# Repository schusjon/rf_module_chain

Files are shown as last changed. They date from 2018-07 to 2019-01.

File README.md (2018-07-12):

# Overview

The aim of the project is to develop a chain of RF-modules which can be connected in series. The most common connector for RF applications is the SMA connector. Because of the high purchase price, the idea to use another connector e.g. PCI Express has existed for quite some time. The main advantage over other connectors is the comparatively low price. Moreover, it can be used up to a frequency of about 500 MHz and the male connector can be easily included on the circuit board. 

[Bild 1]: images/chain.PNG
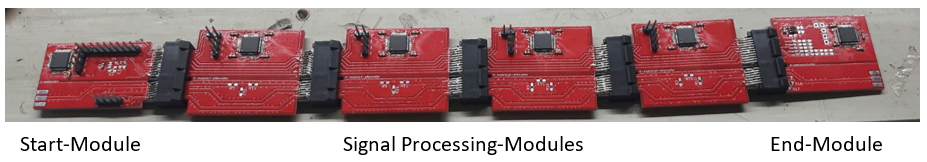
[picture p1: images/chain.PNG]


A means of digital communication should be implemented throughout the chain, an expansion that distinguishes this project from previous, unfinished attempts. The high amount of contacts the PCI-E connector provides facilitates this endeavor.
The chain starts with a special start-module including pin headers for the power supply, as will be explained later.
We expect that the following voltages will cover most conceivable scenarios:

Voltage Rails

|  +5V | -5V  |  3.3V | +12V  | -12V  |
|---|---|---|---|---|

Again, the chosen PCI connector allows for all those different voltage rails and with a current handling of 1A per pin, distributing power to the chain can be done with the same connector.
To feed the chain with the RF-Signal, one SMA connector on the start-module is unavoidable. For further experiments it is useful to add two additional RF inputs. 
These can be used for a reference signal or any auxiliary signal. In this project we limit ourselves to designing only the traces and basic interfacing for these signals on the boards. 
To receive the signal from the chain, a further SMA connecter is used on the end module. 

## Signal Chain

The signal chain consists of different modules, all of which have a few components and properties in common:
All links within the chain are established with PCI-E 36 connectors, all modules bear either a straddle mount receptacle, card-edge fingers or both to interface with neighboring modules.
Each one is equipped with a STM32F0 microprocessor for data transmission and control purposes. 
They utilize their internal RC oscillator to help minimize cost and prevent clock spill into the RF signals.
A 4pin header is used to program these processors with a ST-Link USB adaptor. A fifth pin adjacent to the programming connector serves in conjunction with a jumper as a power switch for the processor on this module only. 
Connected during normal operation, the jumper can be removed to shut off the processor of a single module without cutting the power of the rest of the chain. (Due to the nature of the daisy chain, communication will be interrupted as well)
The modules incorporate separate ground planes for RF and data/power circuits. 
The RF ground is continuous on the back of the PCB to improve impedance control. Via stitching and a defined trace width and aura (1mm width, 0.15mm aura) of the RF signal traces on the 1.6mm FR4 PCBs yield an impedance close to 50 Ohms (with the properties of the laminate causing deviations). 
A series of solder pads on the modules allow linking those ground planes at virtually any point in the chain if the need arises.

[Bild 2]: images/bottom.PNG
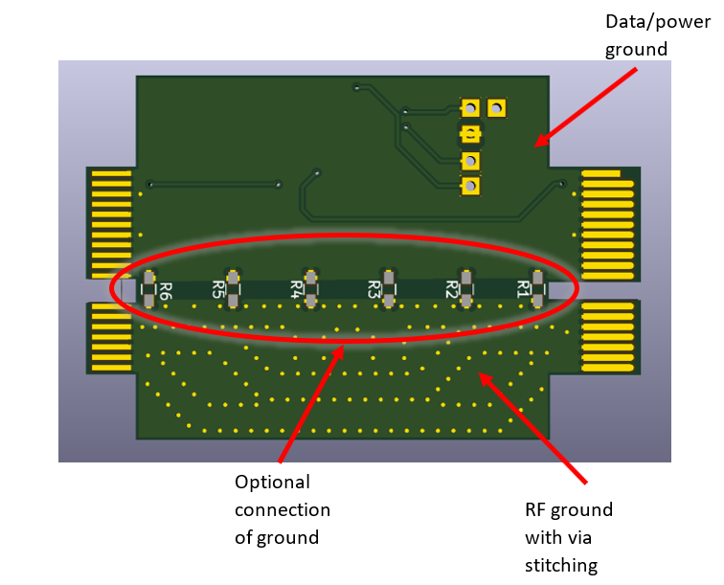
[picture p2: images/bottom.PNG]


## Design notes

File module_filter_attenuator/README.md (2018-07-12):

# Filter Attenuator Modules

**The filter/attenuator modules** come in two topologies, PI and T. Solder pads (0603 in metric system) allow for custom filters and attenuators. Identical except for the filter configuration, both modules pass REF and AUX unaltered. The processor can be programmed with information about the implemented filter, making its properties computer-readable. While it does not provide any control functionality at this moment, it is conceivable to utilize RF switches to select different attenuations or frequencies. (the SKY 13XXX range from Skyworks Solutions appears to be promising and cost effective)

The prototype PI-attenuator was equipped with 18 Ohms for R7 and R9 and 300 ohms for R8, selected from the E24 series.

The calculated values for 3dB attenuation would have been 17.6 ohms and 292 ohms respectively.

The T attenuator was implemented with 10dB of attenuation, with  the resistor values 27 and 36 ohms ( instead of the theoretical 26.0 and 35.1 ohms)

[Bild 1]: images/bottom-pi-att.PNG

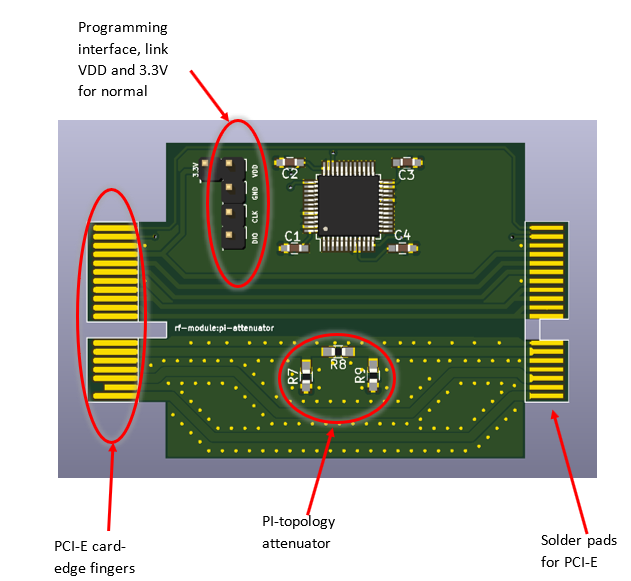
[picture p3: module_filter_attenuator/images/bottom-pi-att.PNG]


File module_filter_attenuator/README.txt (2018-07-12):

R1, R2, R3, R6, R7, R8 werden nicht bestückt!
Filter/Dämpfungsglied vorerst nicht bestücken!

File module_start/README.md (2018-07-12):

# Start Module

**The input/start module** additionally features input connectivity for power and signals:

Standard 2.54mm pin headers serve as power inputs, thus allowing for easy assembly of custom breakout cables. The same holds true for the RX and TX signals, enabling the user to use his favorite UART converter or control the chain with a single board computer. Additional ground pins might be added in following revisions to facilitate interfacing.

The RF signal has a female SMA receptacle, the two additional signals (REF and AUX) terminate to solder pads that allow connection of coax cables or pin headers.

The input module also hosts a 3.3V regulator that supplies the whole chain. Solder pads are prepared for different types of SOT 23-5 LDOs with their respective circuitry.

At the moment, the installed processor does not add any exclusive functionality and is simply another link in the daisy chain. A possible future implementation would be the detection of input signals or power supply voltages to help troubleshoot larger experimental setups. Conversely, this component could be cut entirely for cost optimization. Especially with suitable detectors like the AD 8307 being in the 10€ price range.

[Bild 1]: images/start_description.PNG

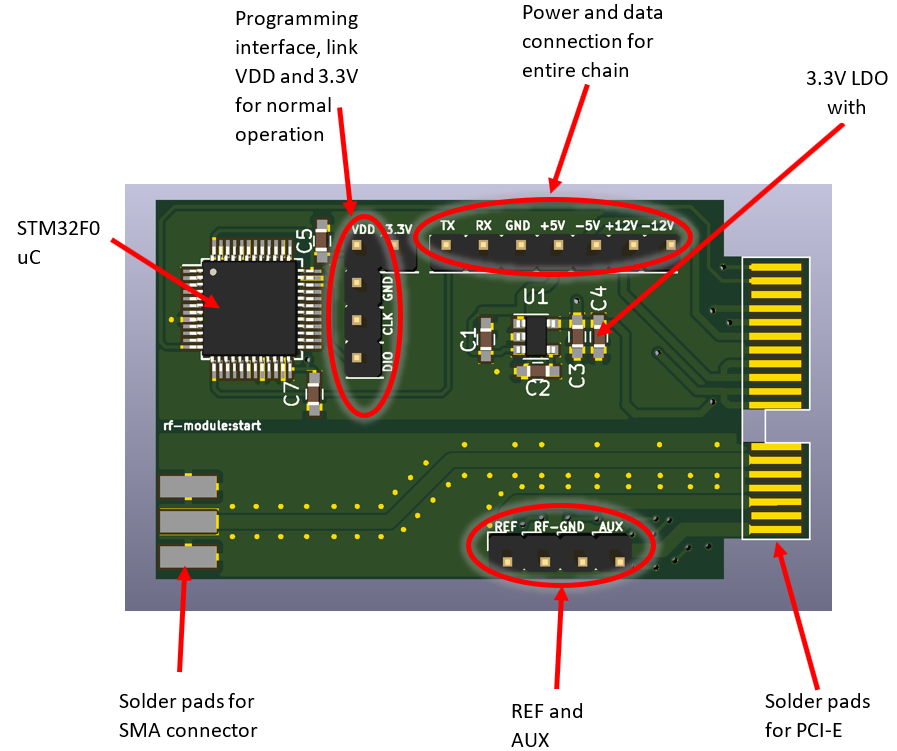
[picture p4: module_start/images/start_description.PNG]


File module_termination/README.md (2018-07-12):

# Termination Module

**The termination/end module** includes status LEDs to check the power busses and the link status of the chain. Two of them are controlled by the uC and are user programmable. The two additional RF signals, REF and AUX are terminated on the module with 50 ohms.

The output is implemented as a female SMA receptacle.

The prototype carries its own 3.3V LDO due to the critical role of the embedded processor. This last link in the chain reorganizes all data received from preceding modules and transmits them to the control computer. This individual power supply could have offered additional debugging and troubleshooting information but was deemed unnecessary in early test and was therefore omitted from later designs.

Further development could include an automated power supply check: A passive resistor network of voltage dividers and pullups should be enough to generate an unambiguous digital pattern that would enable the uC to read the status of the connected supplies.

[Bild 1]: images/bottom_termination.PNG

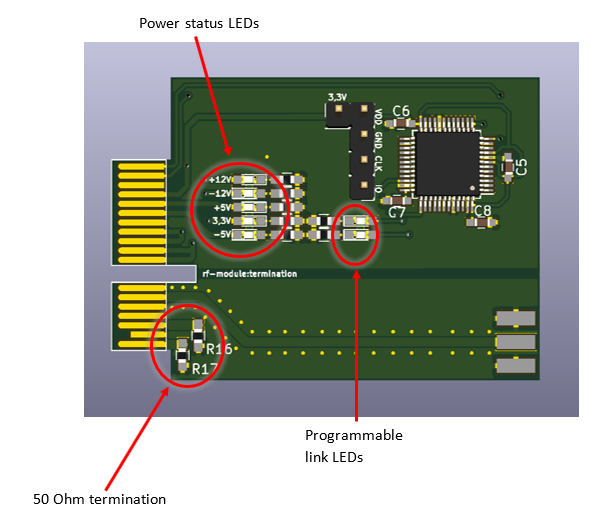
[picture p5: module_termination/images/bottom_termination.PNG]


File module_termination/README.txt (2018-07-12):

R6, R7, R8, R9, R10, R11, R12, R13 werden nicht bestückt!
C2, C4 nicht bestücken! (für anderen Spannungsregler)
Bei LEDs: Punkt markiert Kathode
Widerstände bei Bedarf auf nächst höheren Wert aufrunden

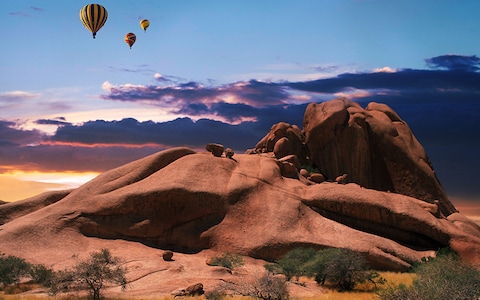
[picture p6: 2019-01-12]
serial_communication/d3.jpg

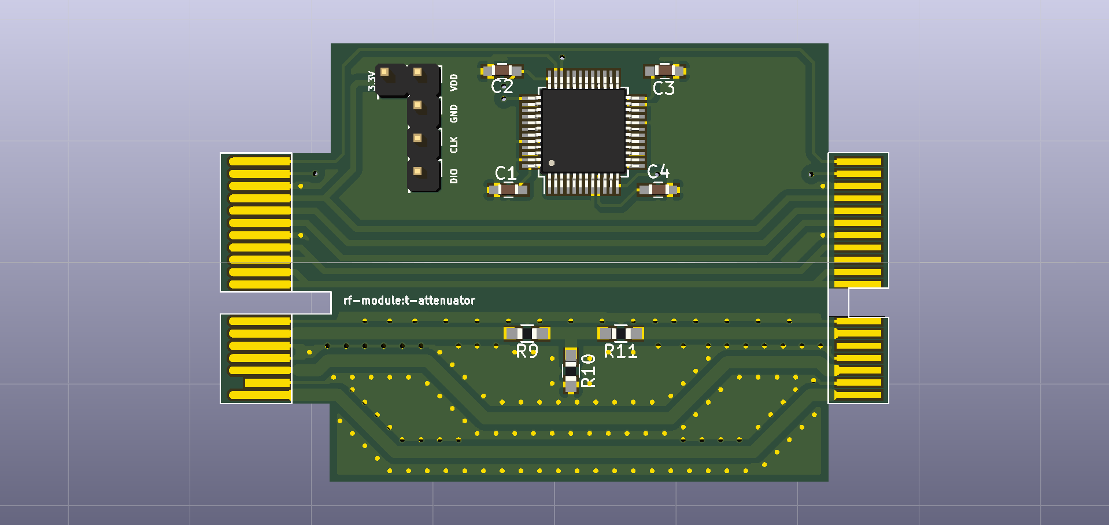
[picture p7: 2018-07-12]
module_filter_attenuator/rflego_t_att_mit_Bauteile.png

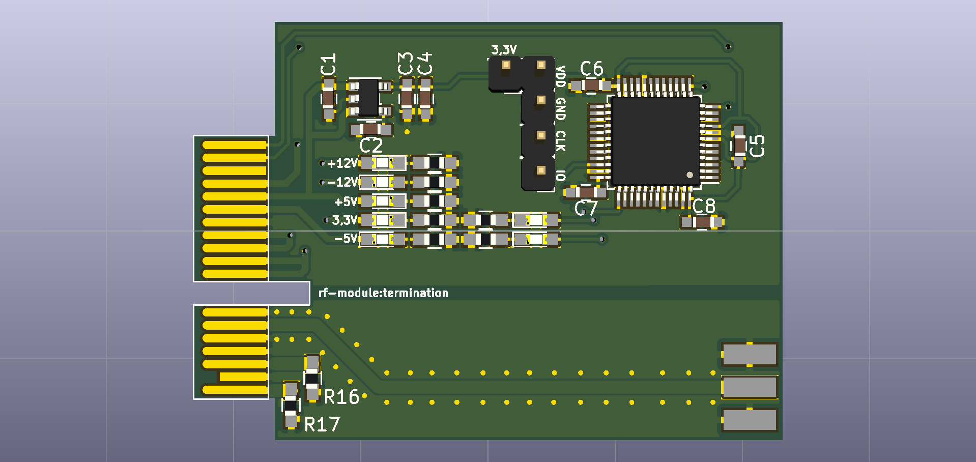
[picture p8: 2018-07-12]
module_termination/rflego_termination_mit_Bauteile.png

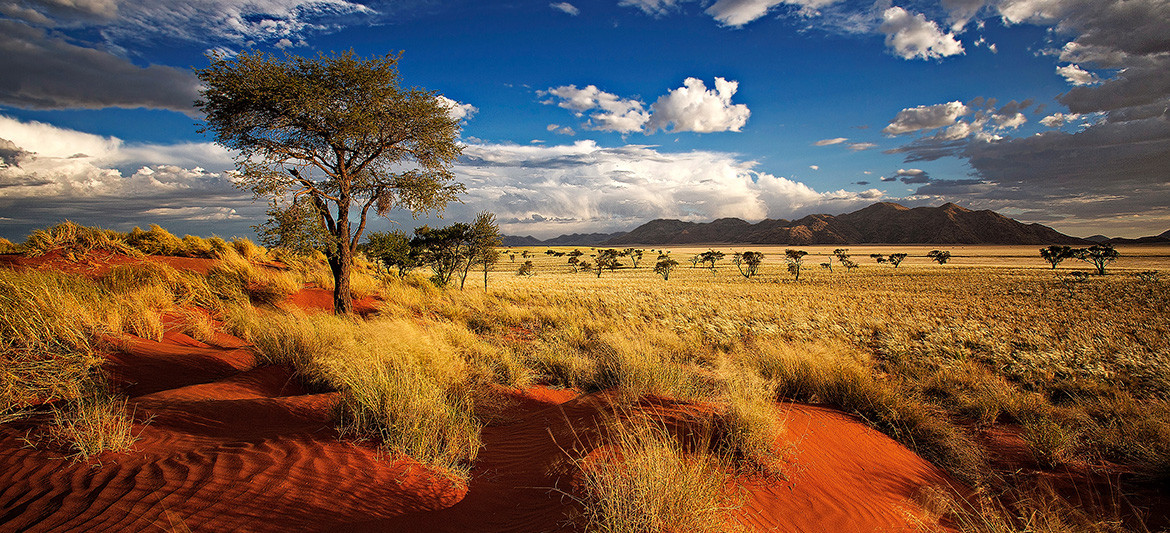
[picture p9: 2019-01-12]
serial_communication/d1.jpg

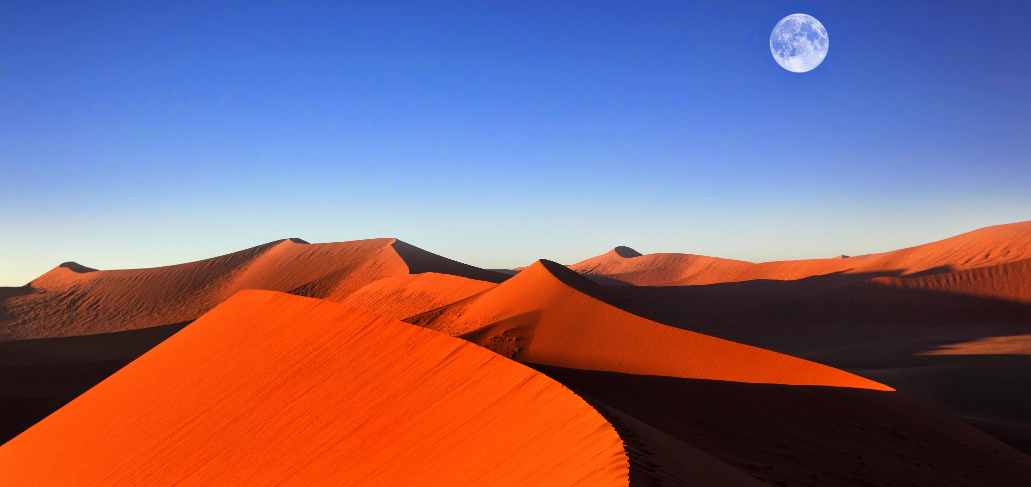
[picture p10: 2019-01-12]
serial_communication/d2.jpg

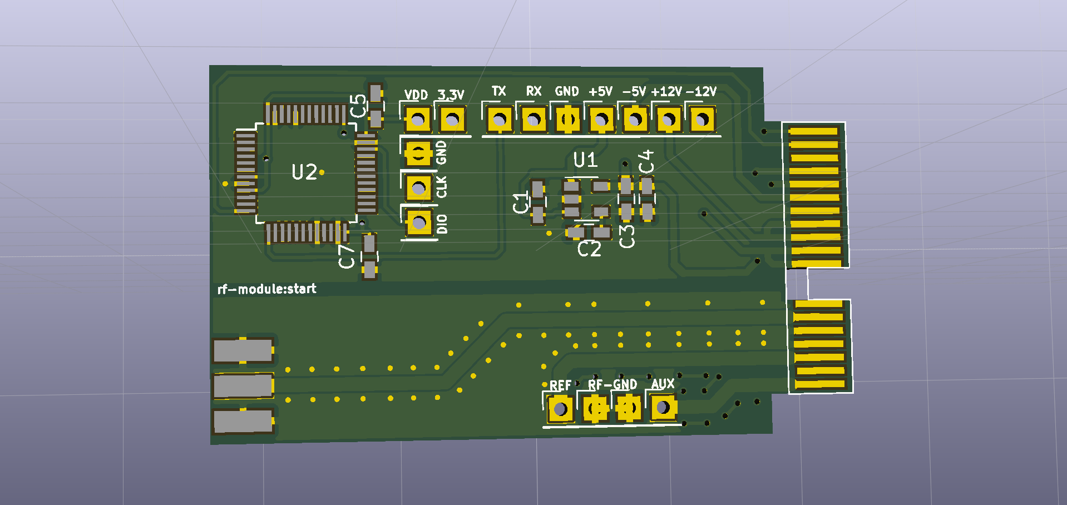
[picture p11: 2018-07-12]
module_start/rflego.png

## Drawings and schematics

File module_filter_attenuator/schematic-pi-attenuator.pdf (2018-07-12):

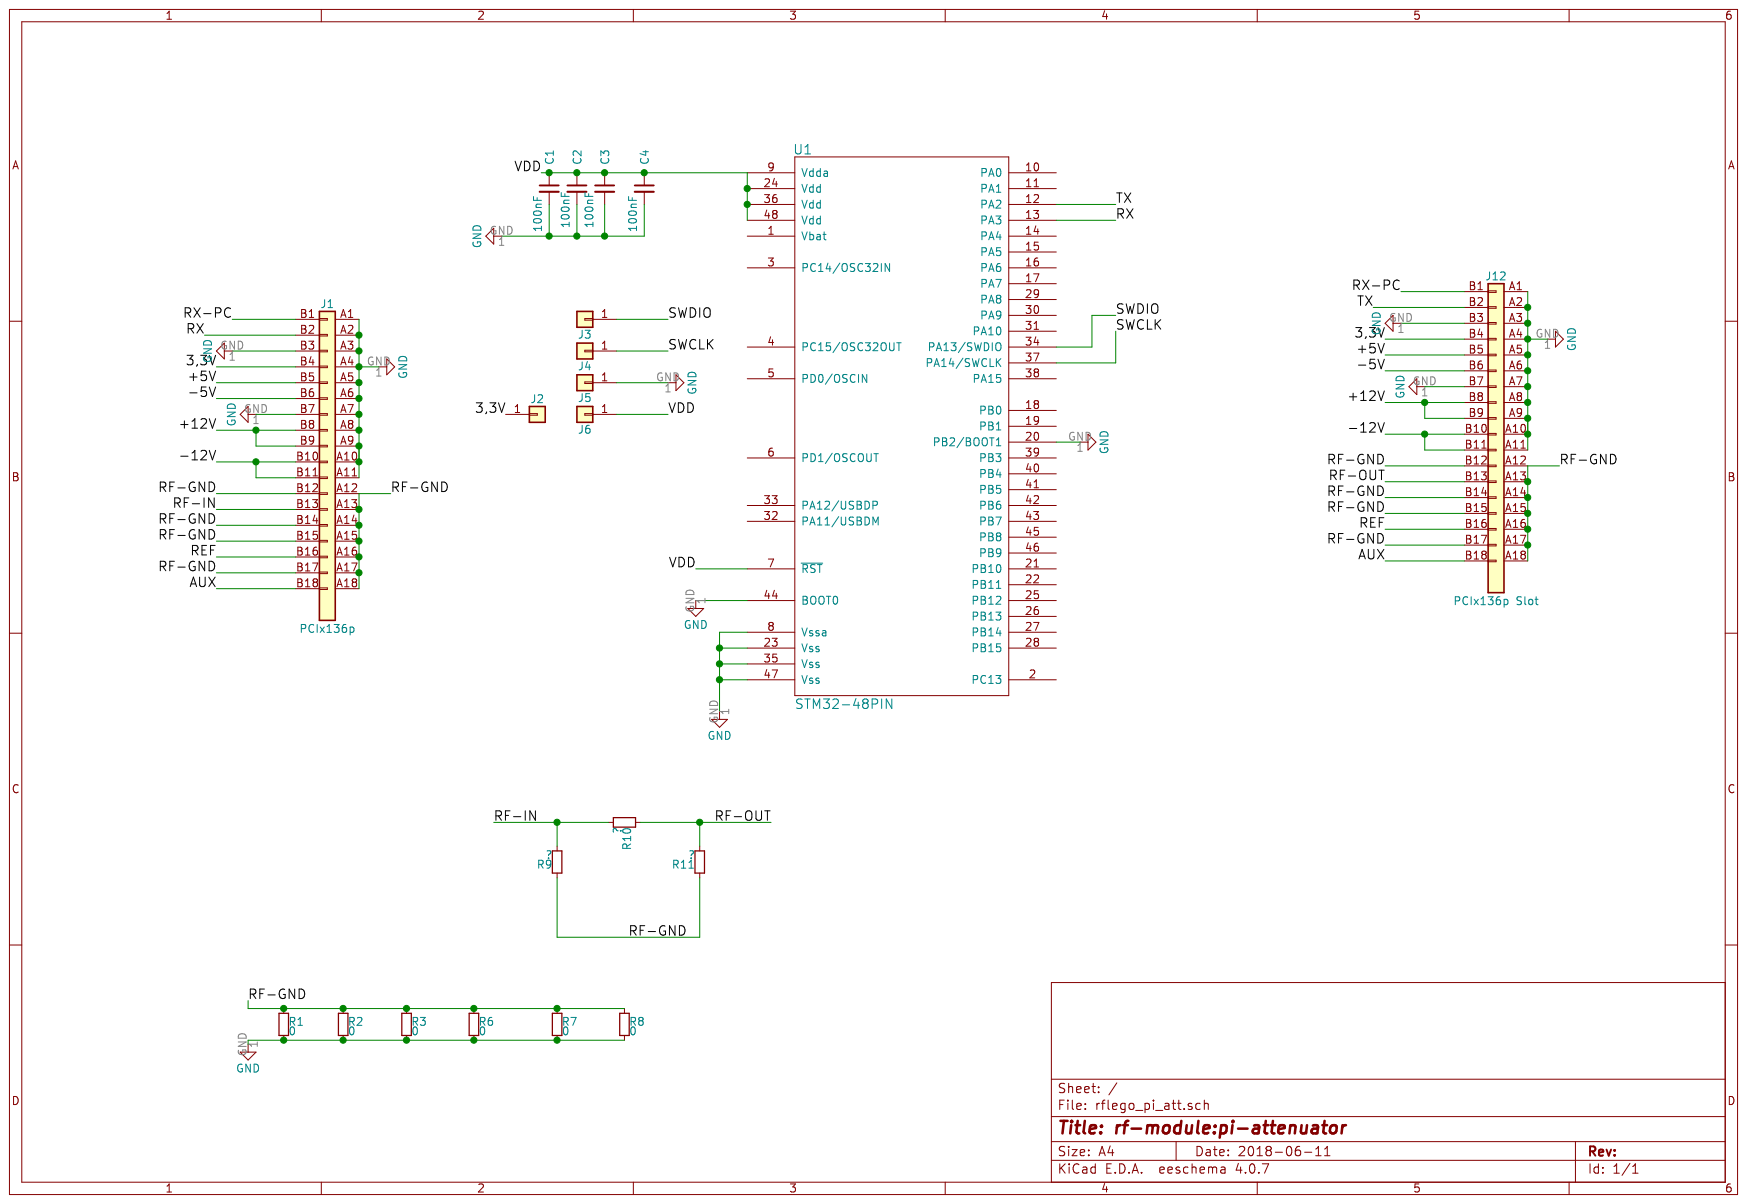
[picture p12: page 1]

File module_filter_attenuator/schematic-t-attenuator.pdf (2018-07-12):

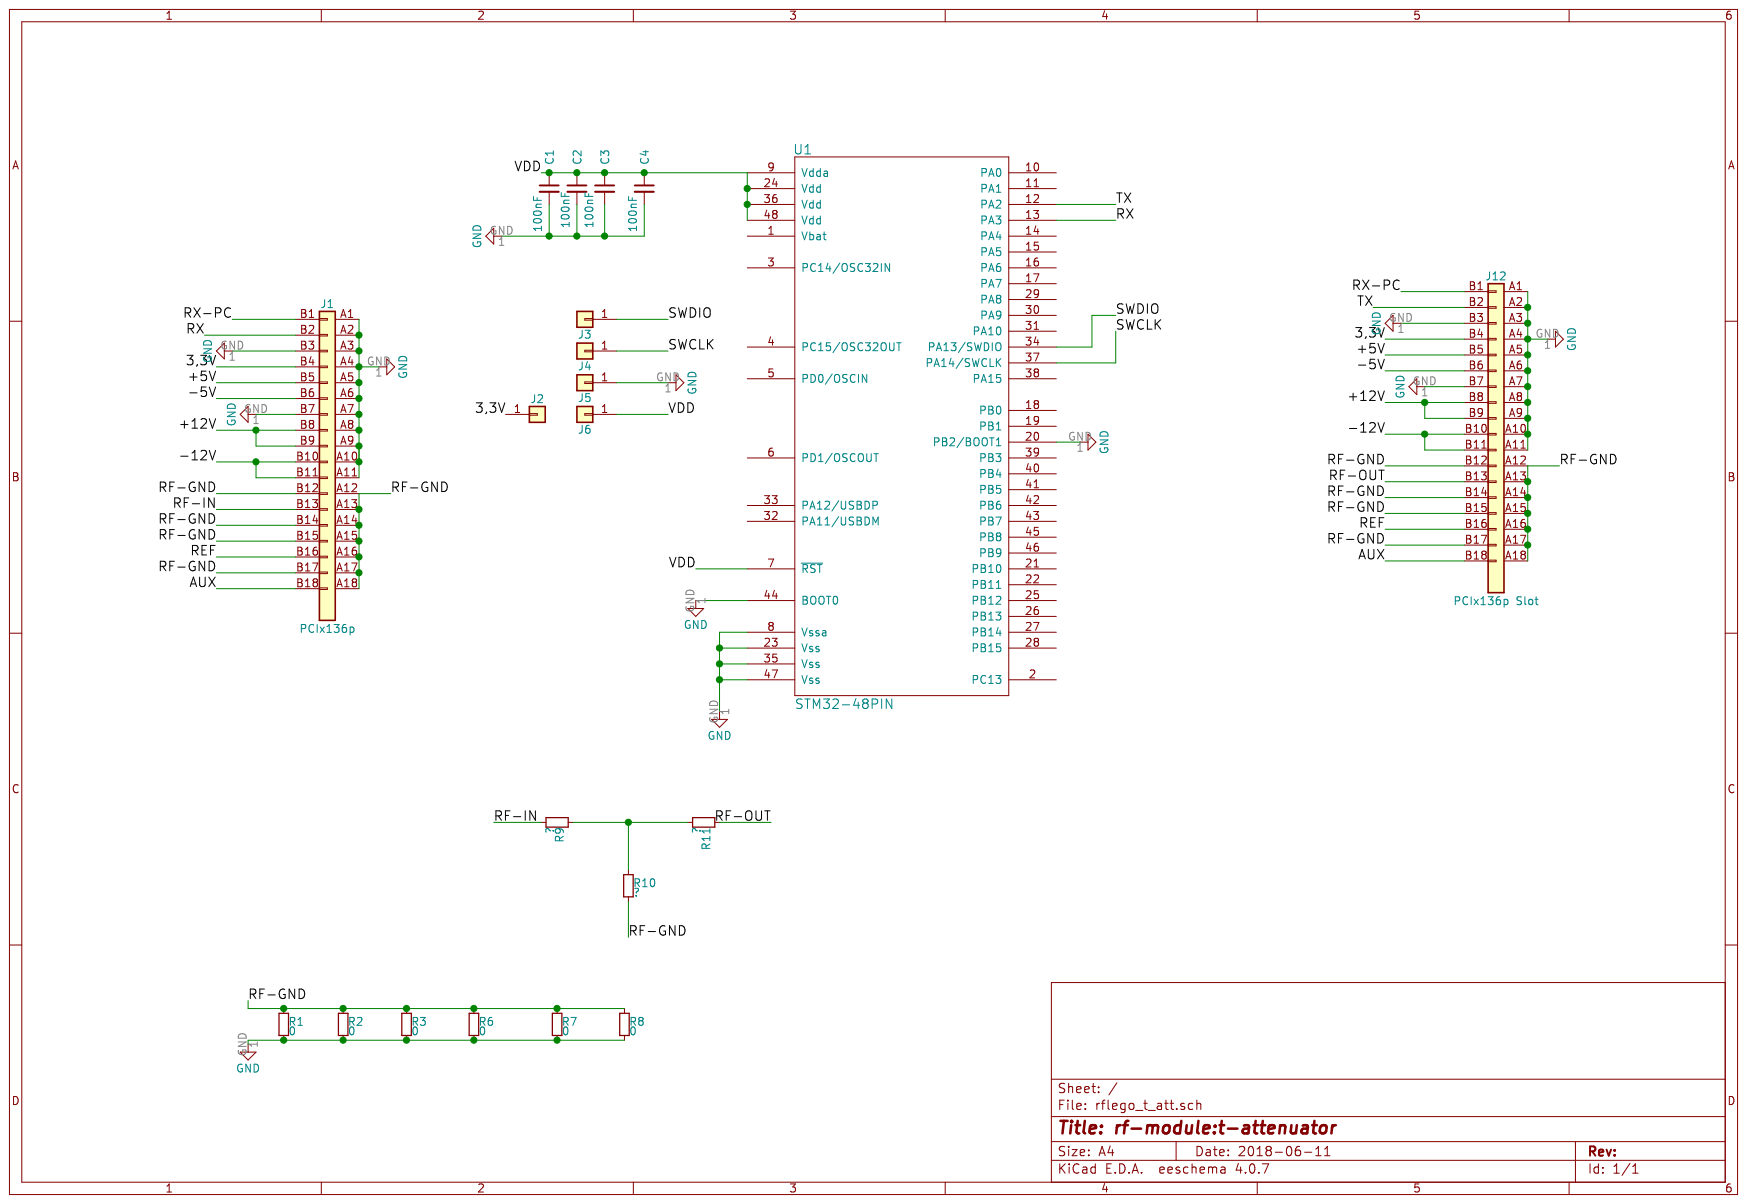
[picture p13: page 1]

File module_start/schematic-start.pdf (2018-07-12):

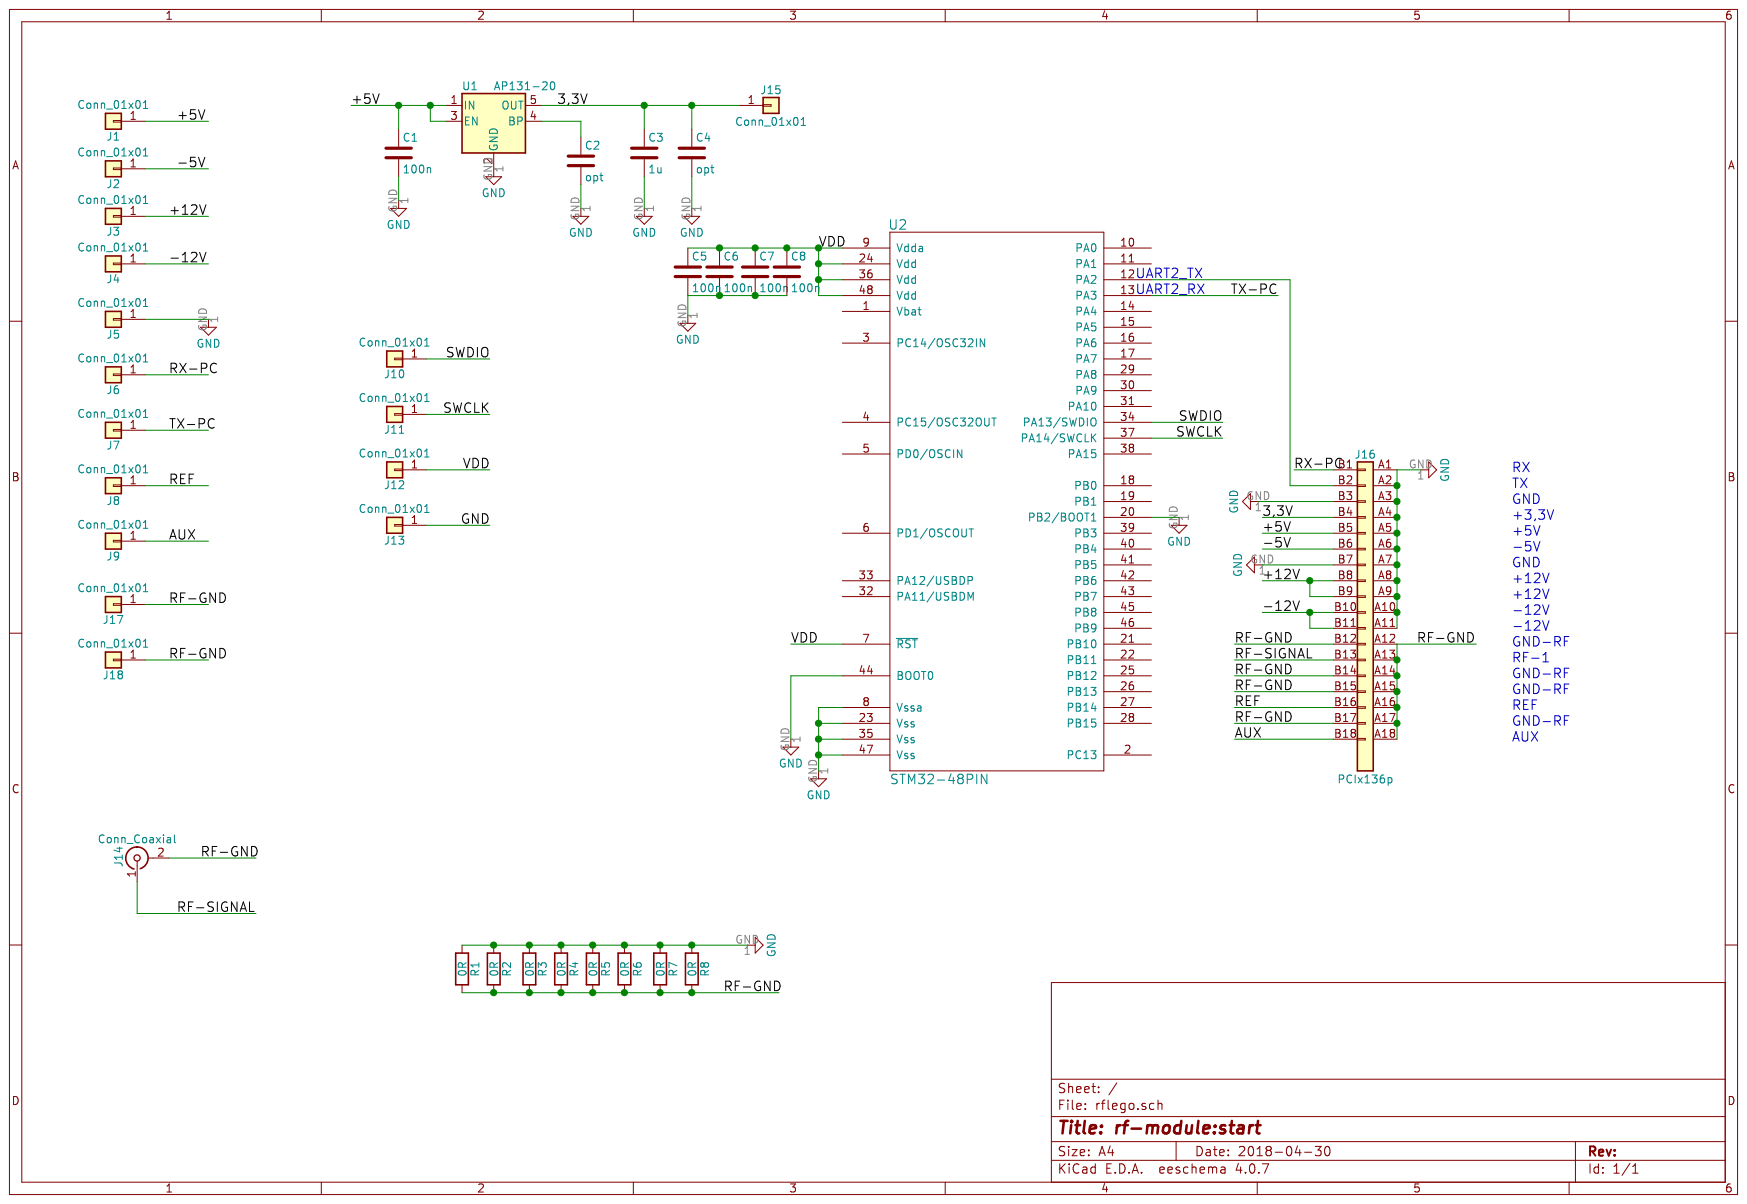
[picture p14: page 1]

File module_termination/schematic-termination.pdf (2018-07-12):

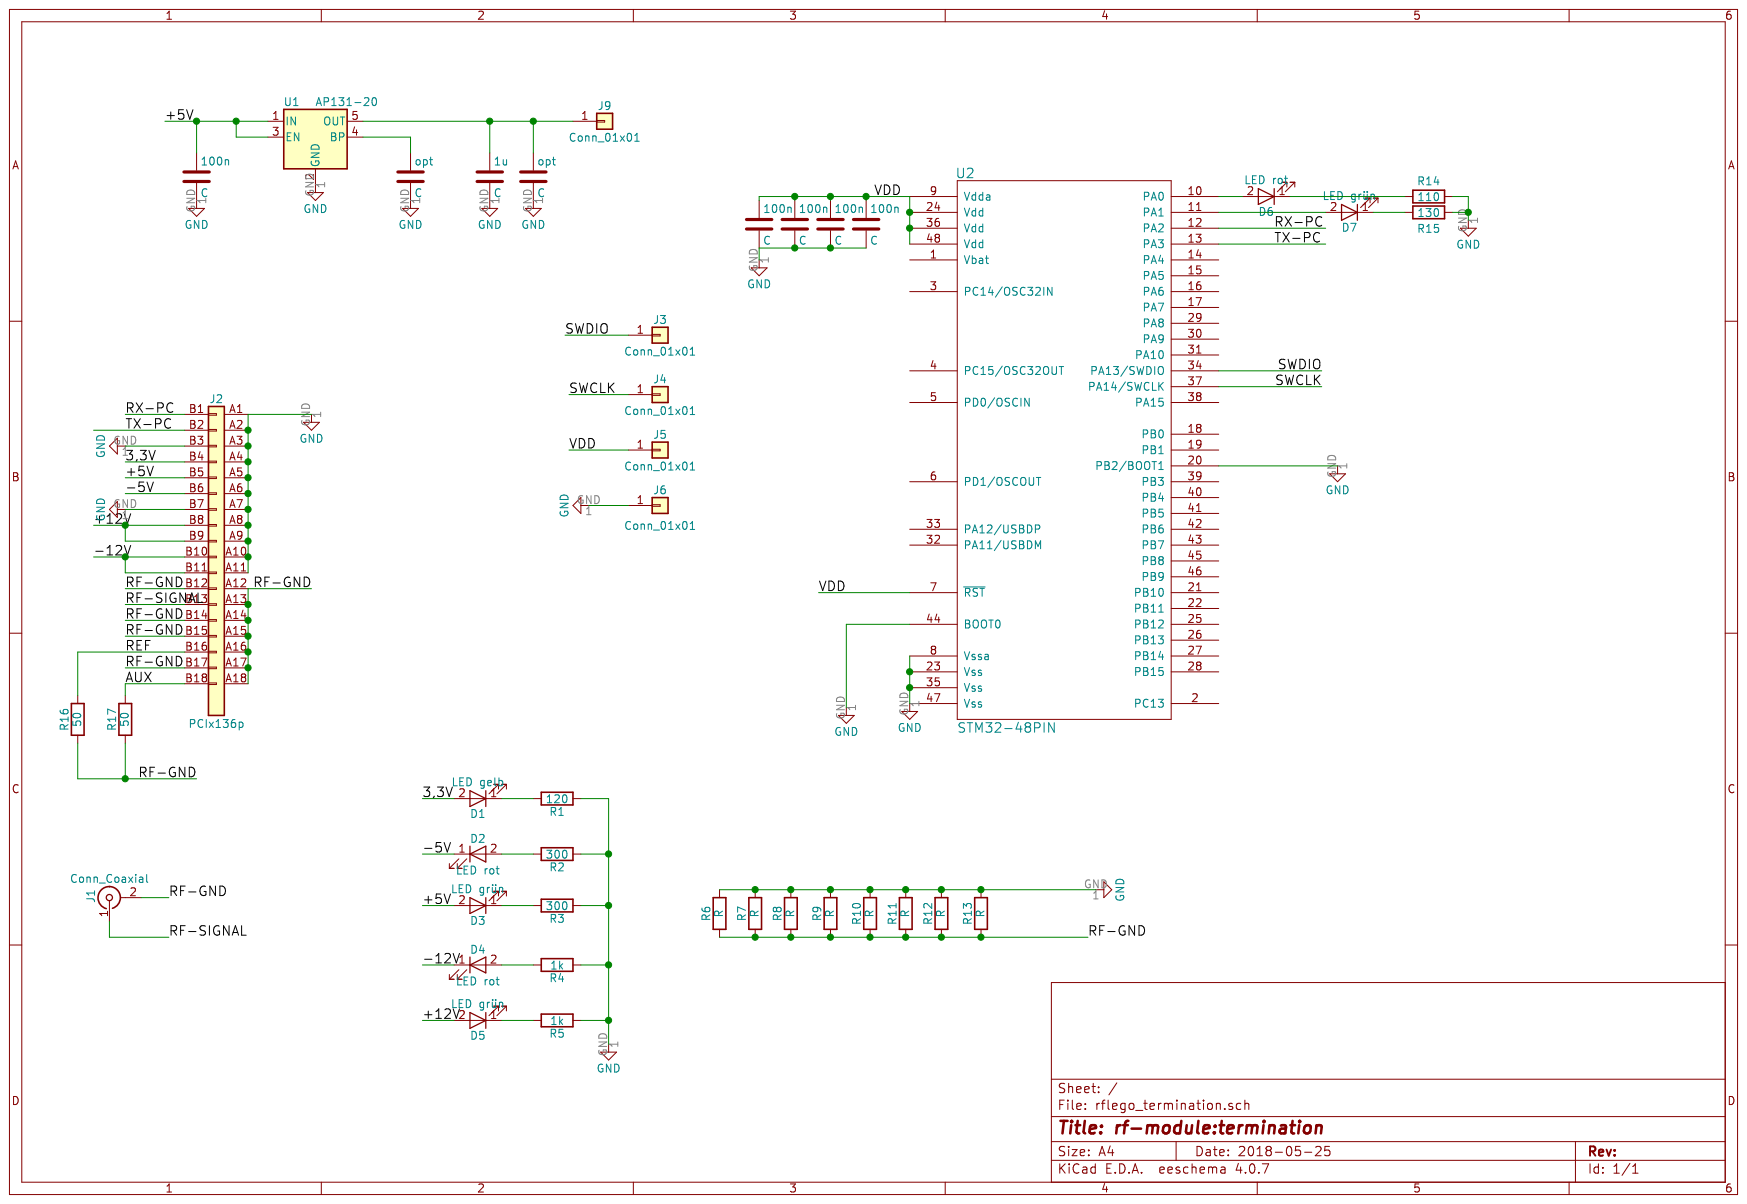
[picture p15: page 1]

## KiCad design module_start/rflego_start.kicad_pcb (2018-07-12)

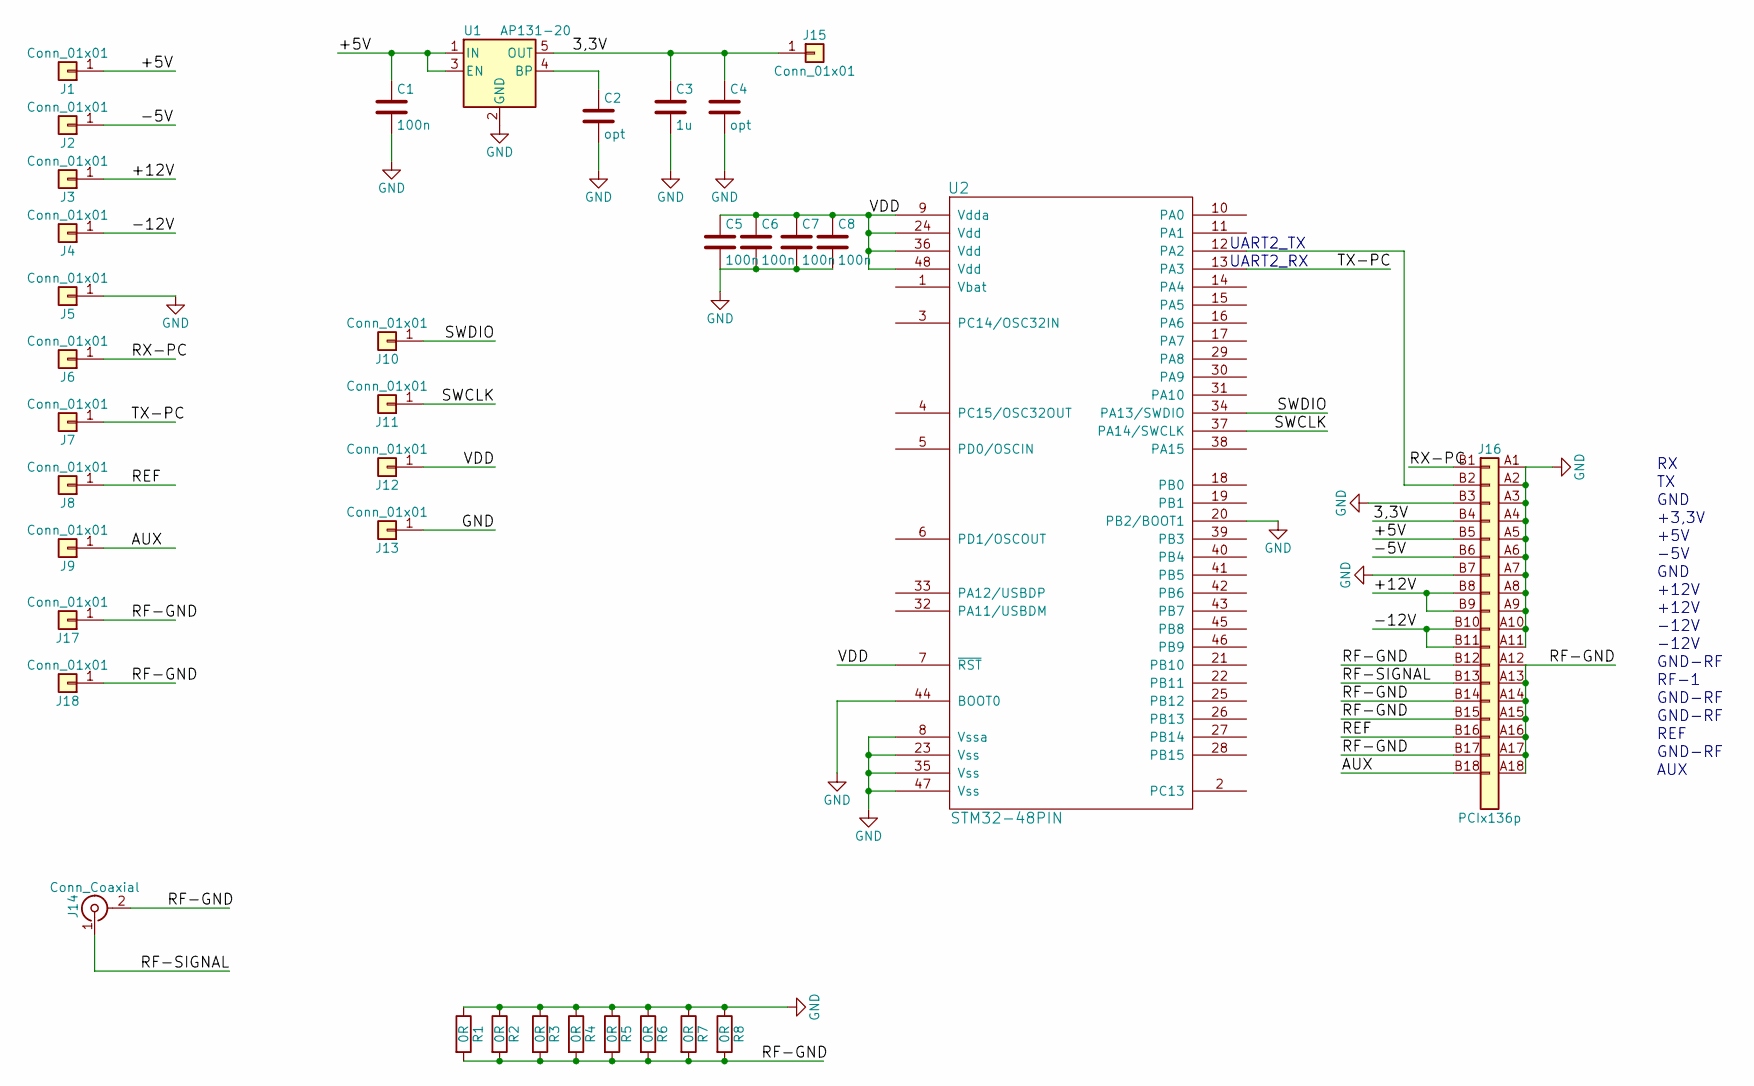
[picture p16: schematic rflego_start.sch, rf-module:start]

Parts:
C1, C5, C6, C7, C8: 100n; C_0603_HandSoldering
C2, C4: opt; C_0603_HandSoldering
C3: 1u; C_0603_HandSoldering
J1, J2, J3, J4, J5, J6, J7, J8, J9, J10, J11, J12, J13, J15, J17, J18: Conn_01x01; Pin_Header_Straight_1x01_Pitch2.54mm
J14: Conn_Coaxial; CONSMAEDGE
J16: PCIx136p; PCI-EXPRESS-SLOT
R1, R2, R3, R4, R5, R6, R7, R8: 0R; R_0603_HandSoldering
U1: AP131-20; SOT-23-5
U2: STM32-48PIN; LQFP-48_7x7mm_Pitch0.5mm

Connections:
/3,3V: C3.1, C4.1, J15.1, J16.B4 (Pin_4), U1.5 (OUT)
/+5V: C1.1, J1.1, J16.B5 (Pin_5), U1.1 (IN), U1.3 (EN)
/+12V: J3.1, J16.B8 (Pin_8), J16.B9 (Pin_9)
/-5V: J2.1, J16.B6 (Pin_6)
/-12V: J4.1, J16.B10 (Pin_10), J16.B11 (Pin_11)
/AUX: J9.1, J16.B18 (Pin_18)
/REF: J8.1, J16.B16 (Pin_16)
/RF-GND: J14.2 (Ext), J16.A12, J16.A13, J16.A14, J16.A15, J16.A16, J16.A17, J16.A18, J16.B12 (Pin_12), J16.B14 (Pin_14), J16.B15 (Pin_15), J16.B17 (Pin_17), J17.1, J18.1, R1.2, R2.2, R3.2, R4.2, R5.2, R6.2, R7.2, R8.2
/RF-SIGNAL: J14.1 (In), J16.B13 (Pin_13)
/RX-PC: J6.1, J16.B1 (Pin_1)
/SWCLK: J11.1, U2.37 (PA14/SWCLK)
/SWDIO: J10.1, U2.34 (PA13/SWDIO)
/TX-PC: J7.1, U2.13 (PA3)
/VDD: C5.1, C6.1, C7.1, C8.1, J12.1, U2.7 (~RST), U2.9 (Vdda), U2.24 (Vdd), U2.36 (Vdd), U2.48 (Vdd)
GND: C1.2, C2.2, C3.2, C4.2, C5.2, C6.2, C7.2, C8.2, J5.1, J13.1, J16.A1 (Pin_19), J16.A2 (Pin_20), J16.A3, J16.A4, J16.A5, J16.A6, J16.A7, J16.A8, J16.A9, J16.A10, J16.A11, J16.B3 (Pin_3), J16.B7 (Pin_7), R1.1, R2.1, R3.1, R4.1, R5.1, R6.1, R7.1, R8.1, U1.2 (GND), U2.8 (Vssa), U2.20 (PB2/BOOT1), U2.23 (Vss), U2.35 (Vss), U2.44 (BOOT0), U2.47 (Vss)
unnamed: C2.1, U1.4 (BP)
unnamed: J16.B2 (Pin_2), U2.12 (PA2)

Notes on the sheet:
GND
+3,3V
+5V
-5V
+12V
-12V
GND-RF
RF-1
REF
AUX
UART2_TX
UART2_RX

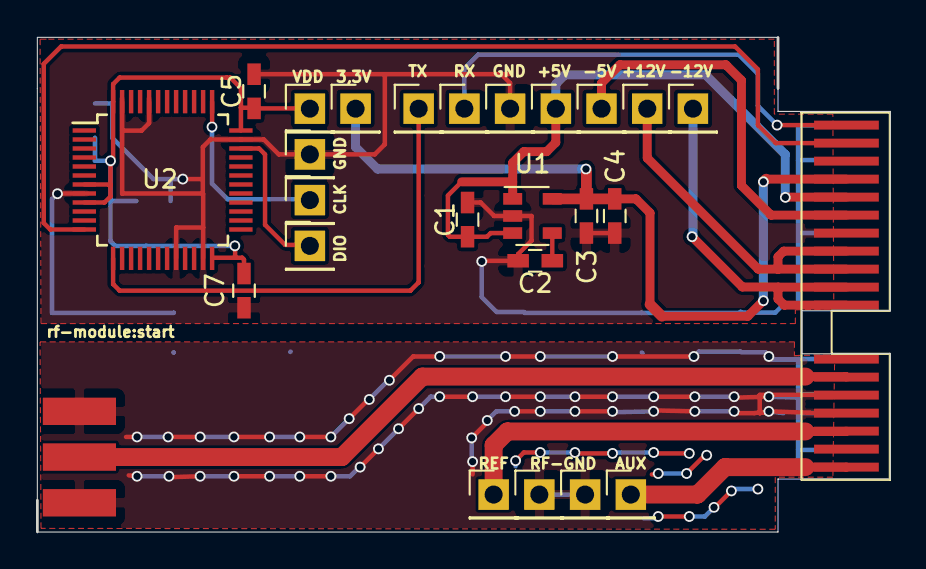
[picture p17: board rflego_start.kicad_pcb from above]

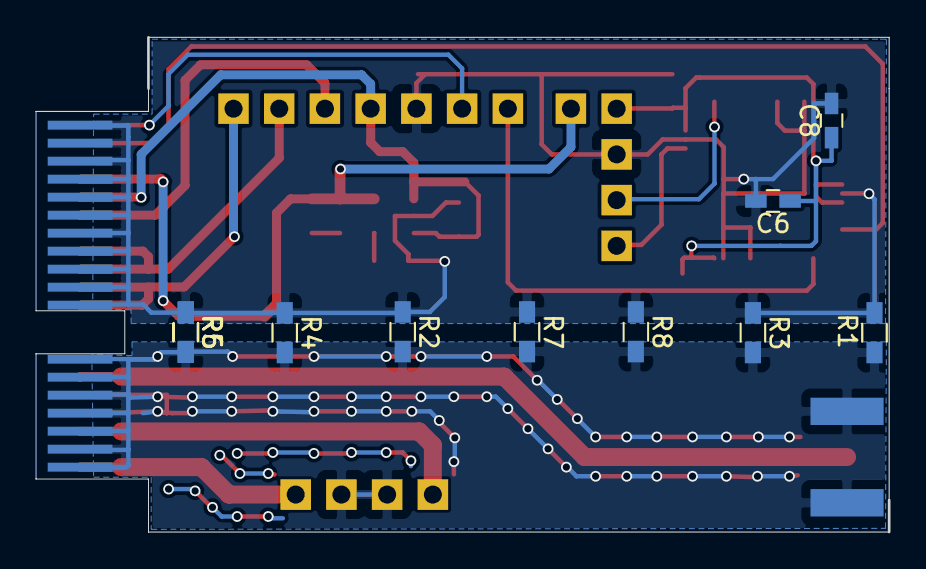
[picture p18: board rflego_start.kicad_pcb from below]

Board: 2 copper layers, 47.4 x 27.5 mm, 36 parts (10 on the bottom side), 17 nets.

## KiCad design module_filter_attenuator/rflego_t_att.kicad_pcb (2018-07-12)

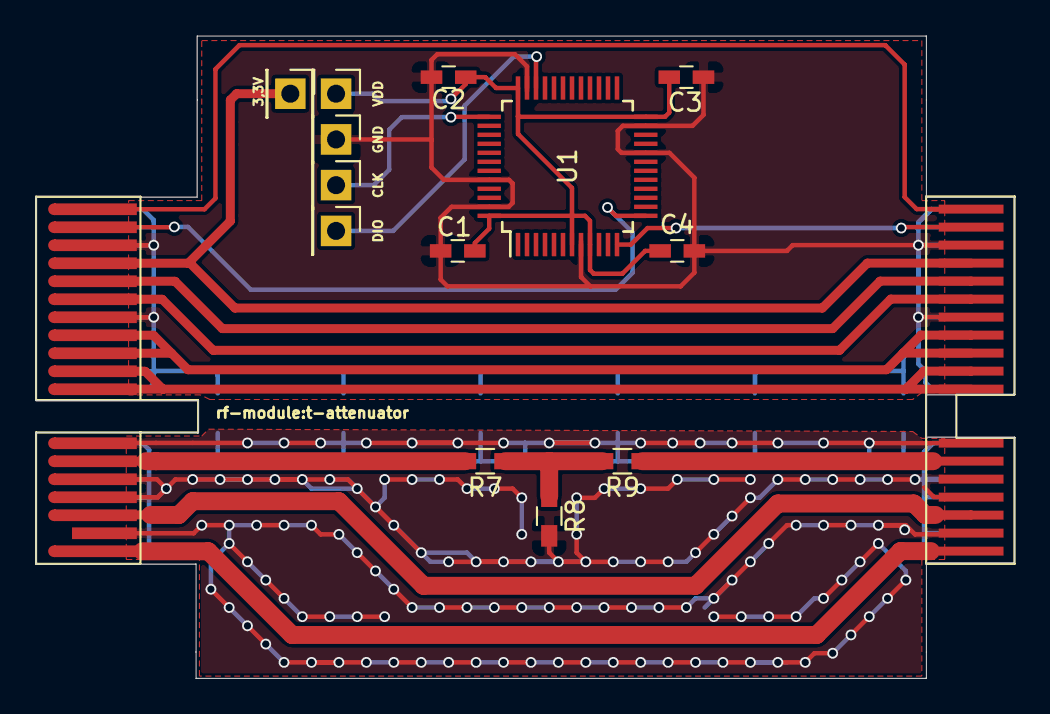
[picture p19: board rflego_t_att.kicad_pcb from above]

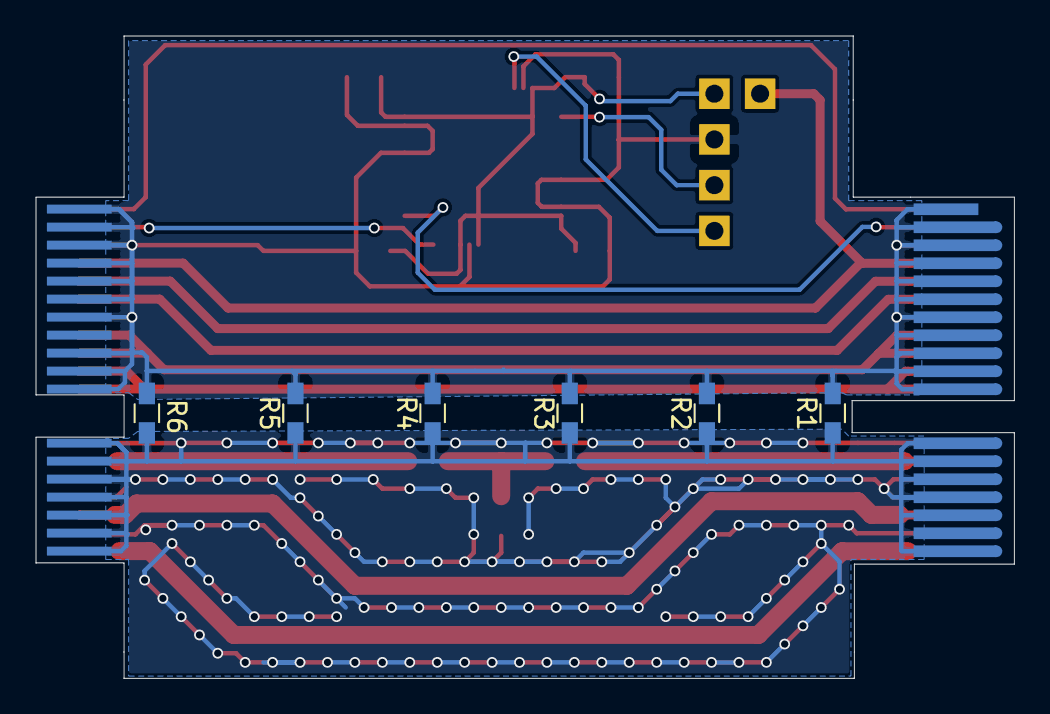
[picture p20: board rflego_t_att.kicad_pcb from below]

Board: 2 copper layers, 54.4 x 35.7 mm, 21 parts (6 on the bottom side), 18 nets.

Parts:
3,3V: Conn_01x01; Pin_Header_Straight_1x01_Pitch2.54mm
C1, C2, C3, C4: 100nF; C_0603_HandSoldering
CLK: Conn_01x01; Pin_Header_Straight_1x01_Pitch2.54mm
DIO: Conn_01x01; Pin_Header_Straight_1x01_Pitch2.54mm
GND: Conn_01x01; Pin_Header_Straight_1x01_Pitch2.54mm
J1: PCIx136p; PCI-EXPRESS
J12: PCIx136p Slot; PCI-EXPRESS-SLOT
R1, R2, R3, R4, R5, R6: 0; R_0603_HandSoldering
R7, R8, R9: ?; R_0603_HandSoldering
U1: STM32-48PIN; LQFP-48_7x7mm_Pitch0.5mm
VDD: Conn_01x01; Pin_Header_Straight_1x01_Pitch2.54mm

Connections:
/3,3V: 3,3V.1, J1.B4, J12.B4
/+5V: J1.B5, J12.B5
/+12V: J1.B8, J1.B9, J12.B8, J12.B9
/-5V: J1.B6, J12.B6
/-12V: J1.B10, J1.B11, J12.B10, J12.B11
/AUX: J1.B18, J12.B18
/REF: J1.B16, J12.B16
/RF-GND: J1.A12, J1.A13, J1.A14, J1.A15, J1.A16, J1.A17, J1.A18, J1.B12, J1.B14, J1.B15, J1.B17, J12.A12, J12.A13, J12.A14, J12.A15, J12.A16, J12.A17, J12.A18, J12.B12, J12.B14, J12.B15, J12.B17, R1.1, R2.1, R3.1, R4.1, R5.1, R6.1, R8.2
/RF-IN: J1.B13, R7.2
/RF-OUT: J12.B13, R9.1
/RX: J1.B2, U1.13
/RX-PC: J1.B1, J12.B1
/SWCLK: CLK.1, U1.37
/SWDIO: DIO.1, U1.34
/TX: J12.B2, U1.12
/VDD: C1.1, C2.1, C3.1, C4.1, U1.7, U1.9, U1.24, U1.36, U1.48, VDD.1
GND: C1.2, C2.2, C3.2, C4.2, GND.1, J1.A1, J1.A2, J1.A3, J1.A4, J1.A5, J1.A6, J1.A7, J1.A8, J1.A9, J1.A10, J1.A11, J1.B3, J1.B7, J12.A1, J12.A2, J12.A3, J12.A4, J12.A5, J12.A6, J12.A7, J12.A8, J12.A9, J12.A10, J12.A11, J12.B3, J12.B7, R1.2, R2.2, R3.2, R4.2, R5.2, R6.2, U1.8, U1.20, U1.23, U1.35, U1.44, U1.47
unnamed: R7.1, R8.1, R9.2

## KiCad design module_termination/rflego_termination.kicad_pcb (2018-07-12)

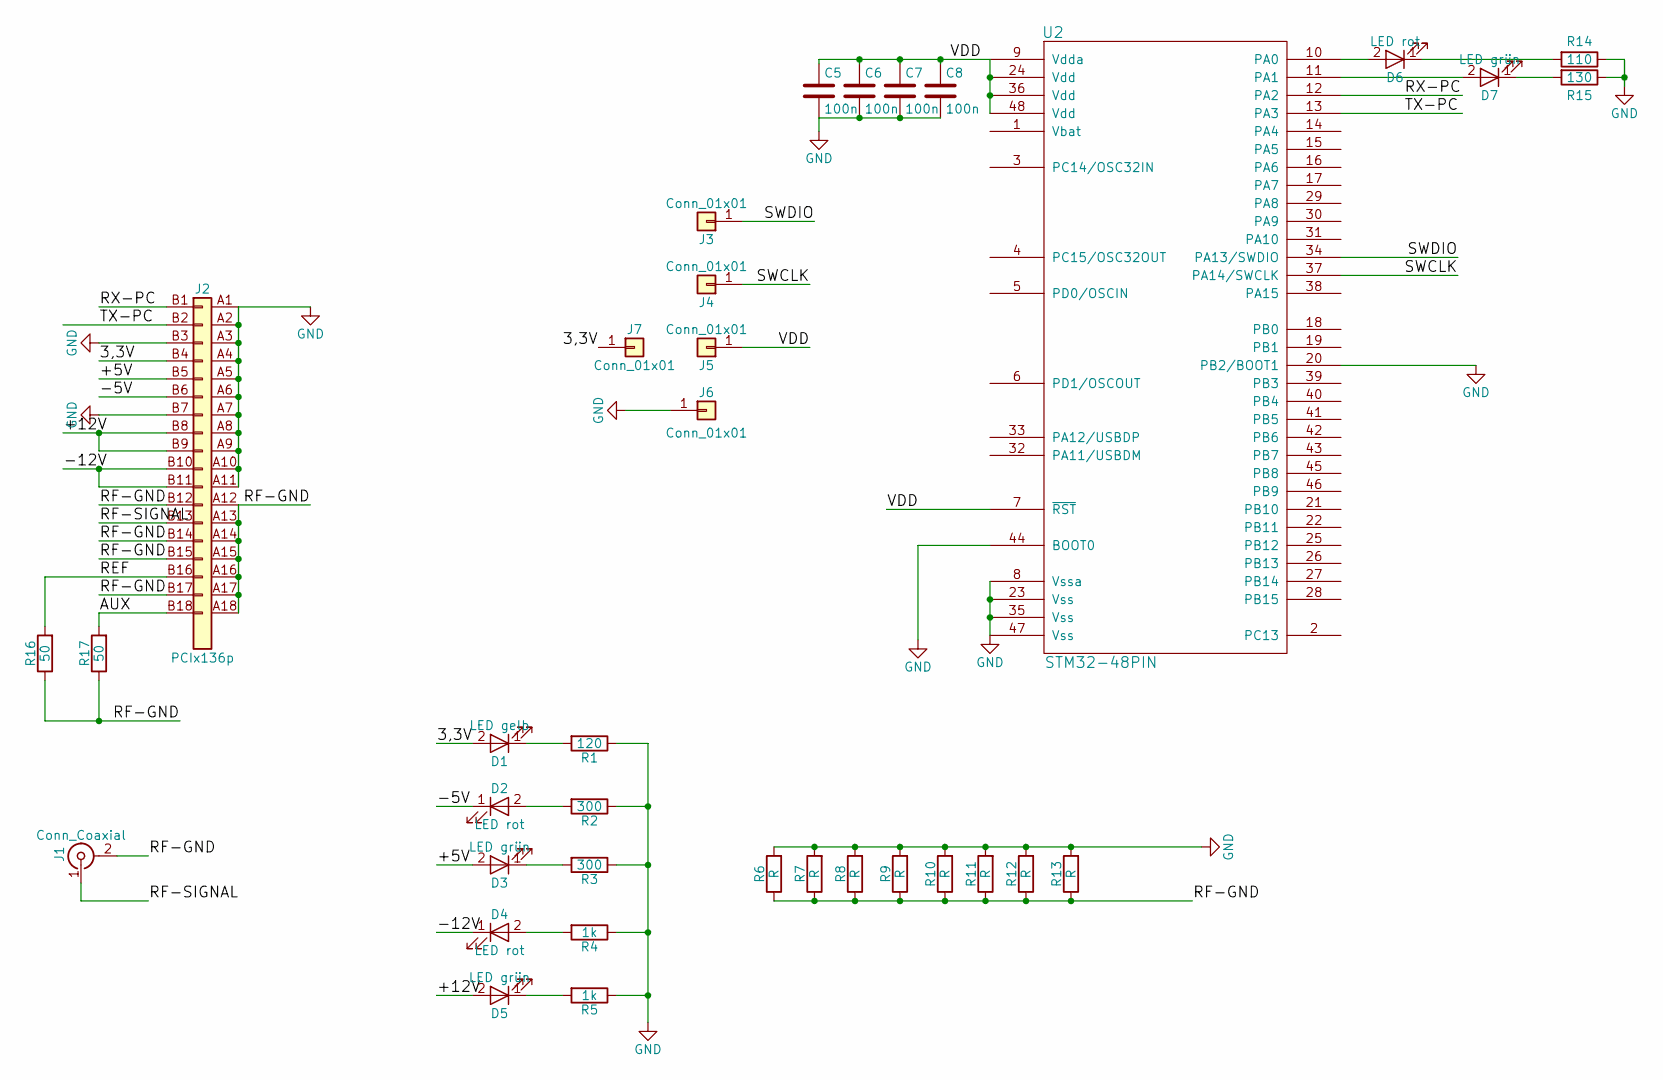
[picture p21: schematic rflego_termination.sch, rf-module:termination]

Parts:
C5, C6, C7, C8: 100n; C_0603_HandSoldering
D1: LED gelb; LED_0603_HandSoldering
D2, D4, D6: LED rot; LED_0603_HandSoldering
D3, D5, D7: LED grün; LED_0603_HandSoldering
J1: Conn_Coaxial; CON-SMA-EDGE
J2: PCIx136p; PCI-EXPRESS
J3, J4, J5, J6, J7: Conn_01x01; Pin_Header_Straight_1x01_Pitch2.54mm
R1: 120; R_0603_HandSoldering
R2, R3: 300; R_0603_HandSoldering
R4, R5: 1k; R_0603_HandSoldering
R6, R7, R8, R9, R10, R11, R12, R13: R; R_0603_HandSoldering
R14: 110; R_0603_HandSoldering
R15: 130; R_0603_HandSoldering
R16, R17: 50; R_0603_HandSoldering
U2: STM32-48PIN; LQFP-48_7x7mm_Pitch0.5mm

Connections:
/3,3V: D1.2 (A), J2.B4 (Pin_4), J7.1
/+5V: D3.2 (A), J2.B5 (Pin_5)
/+12V: D5.2 (A), J2.B8 (Pin_8), J2.B9 (Pin_9)
/-5V: D2.1 (K), J2.B6 (Pin_6)
/-12V: D4.1 (K), J2.B10 (Pin_10), J2.B11 (Pin_11)
/AUX: J2.B18 (Pin_18), R17.2
/REF: J2.B16 (Pin_16), R16.2
/RF-GND: J1.2 (Ext), J2.A12, J2.A13, J2.A14, J2.A15, J2.A16, J2.A17, J2.A18, J2.B12 (Pin_12), J2.B14 (Pin_14), J2.B15 (Pin_15), J2.B17 (Pin_17), R6.1, R7.1, R8.1, R9.1, R10.1, R11.1, R12.1, R13.1, R16.1, R17.1
/RF-SIGNAL: J1.1 (In), J2.B13 (Pin_13)
/RX-PC: J2.B1 (Pin_1), U2.12 (PA2)
/SWCLK: J4.1, U2.37 (PA14/SWCLK)
/SWDIO: J3.1, U2.34 (PA13/SWDIO)
/TX-PC: J2.B2 (Pin_2), U2.13 (PA3)
/VDD: C5.1, C6.1, C7.1, C8.1, J5.1, U2.7 (~RST), U2.9 (Vdda), U2.24 (Vdd), U2.36 (Vdd), U2.48 (Vdd)
GND: C5.2, C6.2, C7.2, C8.2, J2.A1 (Pin_19), J2.A2 (Pin_20), J2.A3, J2.A4, J2.A5, J2.A6, J2.A7, J2.A8, J2.A9, J2.A10, J2.A11, J2.B3 (Pin_3), J2.B7 (Pin_7), J6.1, R1.1, R2.1, R3.1, R4.1, R5.1, R6.2, R7.2, R8.2, R9.2, R10.2, R11.2, R12.2, R13.2, R14.1, R15.1, U2.8 (Vssa), U2.20 (PB2/BOOT1), U2.23 (Vss), U2.35 (Vss), U2.44 (BOOT0), U2.47 (Vss)
unnamed: D1.1 (K), R1.2
unnamed: D2.2 (A), R2.2
unnamed: D3.1 (K), R3.2
unnamed: D4.2 (A), R4.2
unnamed: D5.1 (K), R5.2
unnamed: D6.1 (K), R14.2
unnamed: D6.2 (A), U2.10 (PA0)
unnamed: D7.1 (K), R15.2
unnamed: D7.2 (A), U2.11 (PA1)

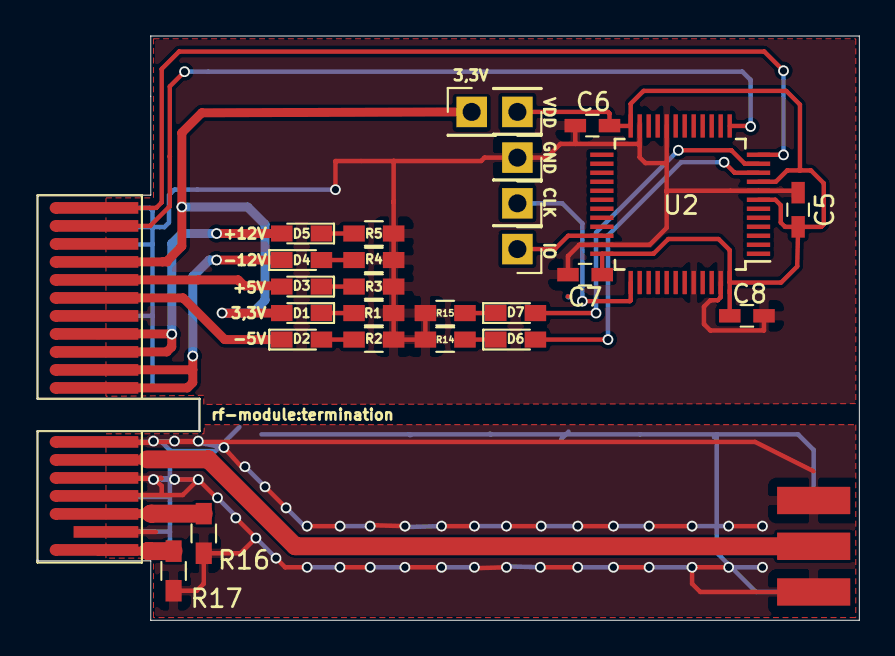
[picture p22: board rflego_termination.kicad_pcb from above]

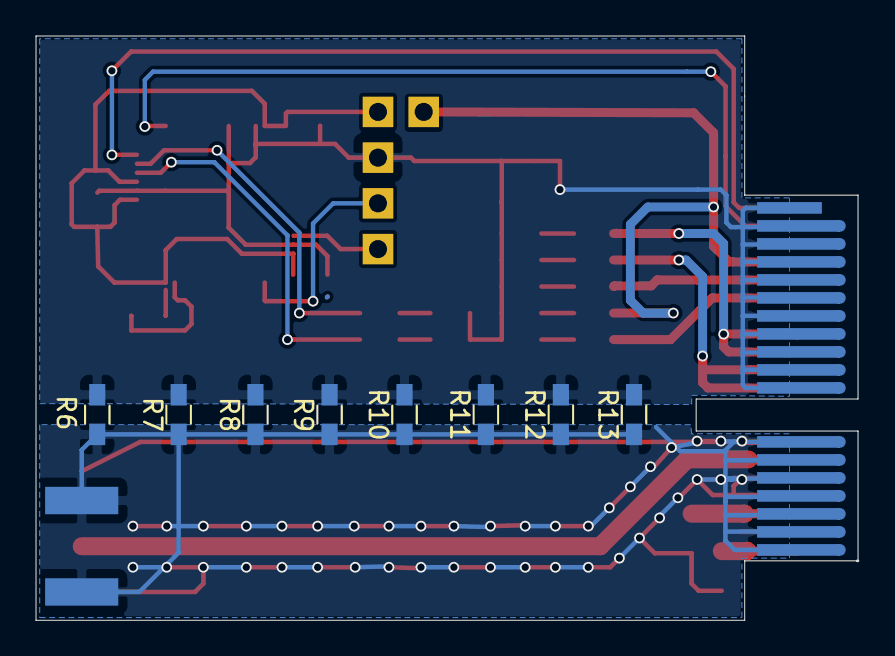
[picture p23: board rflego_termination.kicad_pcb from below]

Board: 2 copper layers, 45.7 x 32.5 mm, 36 parts (8 on the bottom side), 24 nets.

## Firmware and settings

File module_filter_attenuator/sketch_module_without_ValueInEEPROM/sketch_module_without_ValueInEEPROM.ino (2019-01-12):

/*
 Programmierung auf Zwischenmodulen wenn in der Kette
 */

/*
+ * Protokoll
+ *        
+ * Byte 1: a                      for Number of Modules                   From PC
+ *         b                      for Information all                     From PC
+ *         c + Number of module   for Information single                  From PC
+ *         d + Number of module + Information
+ *                                for writing Information to EEPROM       From PC
+ *         
+ * Information all:        
+ * Maximum Number of Modules: 16
+ * 6 Byte per Module => 96 for all if 16 modules available
+ * Byte 2: Own Number                                                     From PC and incremented by µC
+ * Byte 3: a for Gain                                                     From µC
+ *         b for Pie-Module                                               From µC
+ *         c for ...                                                      From µC
+ *         d for ...                                                      From µC
+ * Byte 4: actual value                                                   From µC
+ * Byte 5: upper limit                                                    From µC
+ * Byte 6: low limit                                                      From µC
+ * Byte 7: step size                                                      From µC
+ * ...                                                                    From µC
+ * ...                                                                    From µC
+ * 
+ *  Information single:        
+ * 6 Byte
+ * Byte 2: Actual Number                                                  From PC and decremented by µC
+ * Byte 3: a for Gain                                                     From µC
+ *         b for Pie-Module                                               From µC
+ *         c for ...                                                      From µC
+ *         d for ...                                                      From µC
+ * Byte 4: actual value                                                   From µC
+ * Byte 5: upper limit                                                    From µC
+ * Byte 6: low limit                                                      From µC
+ * Byte 7: step size                                                      From µC
+ * ...                                                                    From µC
+ * ...                                                                    From µC
+ * 
+ * 
+ * Number of modules:
+ * Byte 2: Number                                                         From PC and incremented by µC
+ * 
+ *
+ *
+ * Spacing
+ * Byte n: '_'
+ * 
+ * Termination
+ * Byte x: #                                                              From PC and µC but onely one per String

+*Information in the EEPROM:
+*  address 0: actual value

+ */

#include <EEPROM.h>

// Defines
#define moduleType "a"
#define highLimit  "100"
#define lowLimit "0"
#define stepSize "10"

//Functiondeclaration
void NumberModule();
void informationSingle();
void informationAll();
void getInformationValues();

//global Variables
int informationBuffer[100];
int actualBuffer = 0;
int sendingBuffer = 0;
bool allReceived = false;
//onely needed for last module: 
//char* text = "Write a for Number of Modules, b for Information all, c+Number for Information single (e.g. c5)";

// the setup function runs once when you press reset or power the board
void setup() {
  Serial2.begin(9600);
  informationBuffer[0] = 0;
}

// the loop function runs over and over again forever
void loop() {
  if(Serial2.available() > 0)
  {
    informationBuffer[actualBuffer] = Serial2.read();
    
    if ((informationBuffer[actualBuffer] == '#'))
    {
      allReceived = true;
    }

    

    // Writes Information to Buffer 0 until a, b or c as start for methods
    if(informationBuffer[0] == 'a') // Number of Modules
    {
      if(informationBuffer[1] == '#')
      {
        informationBuffer[1] = '0';
      }
      NumberModule();
    }
    else if(informationBuffer[0] == 'b') // Information all
    { 
      if(informationBuffer[1] == '#')
      {
        informationBuffer[1] = '0';
      }
      informationAll();
    }
    else if(informationBuffer[0] == 'c') // Information single
    {
      informationSingle();
    }
    else if(informationBuffer[0] == 'd') // get Information
    {
      getInformationValues();
    }
    else if(informationBuffer[0] > 0)
    {
      Serial2.write('w');
    }
  }

}

/* Methoden */
void NumberModule()
{
      actualBuffer = actualBuffer + 1;
      if (allReceived)
      {
        informationBuffer[1] = informationBuffer[1] + 1;
        Serial2.write(informationBuffer[0]);
        Serial2.write(informationBuffer[1]);
        Serial2.write('#');
        allReceived = false;
        actualBuffer = 0;
        informationBuffer[0] = 0;
        informationBuffer[1] = 0;
      }
}


void informationAll()
{
  actualBuffer = actualBuffer + 1;
  if (allReceived)
      {
        sendingBuffer = actualBuffer;
        while (sendingBuffer > 1)
        {
          Serial2.write(informationBuffer[actualBuffer - sendingBuffer]);
          sendingBuffer--;
        }
        if(actualBuffer < 5) // For first module in the chain
        {
          Serial2.write(informationBuffer[1] + 1);
        }
        else
        {
          Serial2.write(informationBuffer[actualBuffer - 13] + 1); // Incrementing Counter for modules
        }
        Serial2.write('_');
        Serial2.write(moduleType); // Who am I
        Serial2.write('_');
        byte actValue = EEPROM.read(0);
        Serial2.write(actValue); // Actual Value
        Serial2.write('_');
        Serial2.write(highLimit); // Upper Limit
        Serial2.write('_');
        Serial2.write(lowLimit); // Low Limit
        Serial2.write('_');
        Serial2.write(stepSize); // Step size
        Serial2.write('_');
        Serial2.write('#');
        allReceived = false;
        actualBuffer = 0;
        sendingBuffer = 0;
        informationBuffer[0] = 0;
        informationBuffer[1] = 0;
      }
}

void informationSingle()
{
  actualBuffer = actualBuffer + 1;
  if (allReceived)
      {
        Serial2.write('c');
        Serial2.write(informationBuffer[1] - 1);
        
        
        if(informationBuffer[1] == '1')           // 1 because only decremented when received at next module
        {
          Serial2.write('_');
          Serial2.write(moduleType); // Who am I
          Serial2.write('_');
          byte actValue = EEPROM.read(0);
          Serial2.write(actValue); // Actual Value
          Serial2.write('_');
          Serial2.write(highLimit); // Upper Limit
          Serial2.write('_');
          Serial2.write(lowLimit); // Low Limit
          Serial2.write('_');
          Serial2.write(stepSize); // Step size
          Serial2.write('_');
        }
        if(informationBuffer[1] < '1')
        { //mussten alle um eins erniedrigt werden, da ansonsten jedes mal nach dem ersten mit dem 3. Bit weiter übertragen worden wäre und somit Werte gelöscht werden würden
          Serial2.write(informationBuffer[2]);
          Serial2.write(informationBuffer[3]); // Who am I
          Serial2.write(informationBuffer[4]);
          Serial2.write(informationBuffer[5]); // Actual Value
          Serial2.write(informationBuffer[6]);
          Serial2.write(informationBuffer[7]); // Upper Limit
          Serial2.write(informationBuffer[8]);
          Serial2.write(informationBuffer[9]); // Low Limit
          Serial2.write(informationBuffer[10]);
          Serial2.write(informationBuffer[11]); // Step size
          Serial2.write(informationBuffer[12]);
        }
       
        Serial2.write('#');
        allReceived = false;
        actualBuffer = 0;
        sendingBuffer = 0;
        informationBuffer[0] = 0;
        informationBuffer[1] = 0;
      }
}


void getInformationValues()
{
  actualBuffer = actualBuffer + 1;
  if (allReceived)
      {
        Serial2.write('d');
        Serial2.write(informationBuffer[1] - 1);
        
        
        if(informationBuffer[1] == '1')           // 1 because only decremented when received at next module
        {
          EEPROM.write(0, informationBuffer[2]);  // Actual Value
        }
        allReceived = false;
        actualBuffer = 0;
        sendingBuffer = 0;
        informationBuffer[0] = 0;
        informationBuffer[1] = 0;
      }
}

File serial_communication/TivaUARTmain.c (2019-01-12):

//////////////////////////////////////////////////////////////////////////////
//  This program demonstrates the use of the UART feature on the Tiva Stellaris
//  Launchpad.  The micro-controller will respond to buttons in a GUI UART
//  application.   This program is a baseline for many UART features.  The GUI
//  UART application is based on Qt C++ and displays buttons for the LEDs on the
//  micro-controller and will be available on GITHUB.
//  This GUI will become the baseline for many GUI examples.
//  The data sheet for the Tiva C ARM Cortex M4 is lm4f120h5qr.pdf
//////////////////////////////////////////////////////////////////////////////

#include <lm4f120h5qr.h>

char readChar(void);
void printChar(char c);
void printString(char * string);



int main()
{
  char c;
//  To enable and initialize the UART, the following steps are necessary:
//1. Enable the UART module using the RCGCUART register (see page 314).
  SYSCTL->RCGCUART |= 1<<0;  // for UART0

//2. Enable the clock to the appropriate GPIO module via the RCGCGPIO register (see page 310).
  SYSCTL->RCGCGPIO |= 1<<0;  // for GPIO Port A


//To find out which GPIO port to enable, refer to Table 21-5 on page 1134.

//3. Set the GPIO AFSEL bits for the appropriate pins (see page 624). To determine which GPIOs to
//configure, see Table 21-4 on page 1130.
  GPIOA->AFSEL = (1<<1)|(1<<0);


//4. Configure the GPIO current level and/or slew rate as specified for the mode selected (see
//page 626 and page 634).
    GPIOA->PCTL = (1<<0)|(1<<4);


    // GPIO Port Digital Enable
    GPIOA->DEN = (1<<0)|(1<<1);

 /////////////////////////////////////////////////////////////////////////

    // This section discusses the steps that are required to use a UART module. For this example, the
    //UART clock is assumed to be 20 MHz, and the desired UART configuration is:
    //¦ 115200 baud rate
    //¦ Data length of 8 bits
    //¦ One stop bit
    //¦ No parity
    //¦ FIFOs disabled
    //¦ No interrupts
    // BDR = 20,000,000 / (16 * 115,2000) = 10.8507

    // For this example, 16 MHz will be used
    // BDR = 16,000,000 / (16 * 9600) = 104.166666
    // UARTFBD(DIVFRAC) = integer(0.1666667 * 64 + 0.5) = 11

    // With the BRD values in hand...UART configuration is as follows:
    // Disable the UART by clearing the UARTEN bit in the UARTCTL register
    UART0->CTL &= (1<<0);

    // Get the integer portion of the BRD in the UARTIBRD register
    UART0->IBRD = 104;

    // Get the fraction portion of the BRD in the UARTFBRD register
    UART0->FBRD = 11;

    // Desired parameters in the UART Line Control register
    UART0->LCRH = (0x3<<5);   // for 8 bits

    // Clock Source for UART in UART Clock configuration register
    UART0->CC = 0x0;

    /////////////////////////////////////////////////////////////////////////

    // Reenable the UART by setting the UARTEN bit in the UARTCTL register
    // Also Enable the transmit and receive bits in the UARTCTL
    UART0->CTL = (1<<0)|(1<<8)|(1<<9);

    ////////////////////////////////////////////////////////////////////////

    // Configure LED Pins
    SYSCTL->RCGCGPIO |= (1<<5);                 // Enable clock on Port F
    GPIOF->DIR = (1<<1)|(1<<2)|(1<<3);          // LED pins are outputs
    GPIOF->DEN = (1<<1)|(1<<2)|(1<<3);          // Enable digital functions on pins
    GPIOF->DATA &= ~((1<<1)|(1<<2)|(1<<3));    // Turn off LEDs

    ///////////////////////////////////////////////////////////////////////
    // Configure LCD Pins
    // GPIO Port D for LCD Command Direction - output


    while(1)
    {
     // The following functions are for use with Tera Term or Putty to be displayed on
     // Tera Term or Putty must be turned on and setup to match the UART Settings above
     // printString("        Connected!");
     // printString("Enter \"r for red\", \"g for green\", or \"b for blue\":\n\r");

     c = readChar();
     // printChar(c);
     // printString("\n\r");
     switch(c)
      {
      case 'r':
        GPIOF->DATA = 1<<1;   // Red LED
        break;
      case 'b':
        GPIOF->DATA = 1<<2;   // Blue LED
        break;
      case 'g':
        GPIOF->DATA = 1<<3;   // Green LED
        break;
      case 'o':
	GPIOF->DATA &= ~((1<<1)|(1<<2)|(1<<3));  // All LEDs are off
	break;
      default:
        break;
      }
    }
}

char readChar(void)
{
  char c;
  while((UART0->FR & (1<<4)) != 0);
  c = UART0->DR;
  return c;
}

void printChar(char c)
{
  while((UART0->FR & (1<<5)) != 0);
  UART0->DR = c;
}

void printString(char * string)
{
  while(*string)
  {
    printChar(*(string++));
  }
}
